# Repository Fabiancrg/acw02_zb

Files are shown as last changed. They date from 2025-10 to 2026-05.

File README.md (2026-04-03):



| Supported Targets | ESP32-C6 | ESP32-H2 |
| --- |  --- | --- |

# ACW02-ZB Zigbee HVAC Thermostat Controller




# Project Description
ACW02-ZB is an open-source Zigbee-enabled HVAC controller for the Airton (to replace ACW02 WiFi module) series and compatible units. It allows full integration with Zigbee2MQTT, Home Assistant, and other Zigbee ecosystems, providing remote control, monitoring, and diagnostics for air conditioning systems.

### Key Features
- **Zigbee 3.0 End Device**: Compatible with ESP32-C6 and ESP32-H2
- **Full HVAC Control**: Supports on/off, mode, setpoints, fan speed, swing, eco, night, mute, and display
- **Error Diagnostics**: Exposes AC error codes and status via Zigbee attributes (Only one cade currently)
- **Automatic Polling**: Uses Z2M's generic polling framework for unreportable attributes
- **Auto-Rejoin**: Device automatically rejoins Zigbee network after removal or network loss
- **Clean Entity Names**: Optimized for Home Assistant and Zigbee2mqtt UI
- **Factory Reset**: Long-press boot button 5s for full reset
- **Open Hardware**: PCB and schematic files included (Using Seeedstudio Xiao ESP32-C6)

### Architecture
- **Firmware**: ESP-IDF C code for Zigbee stack, HVAC protocol, and attribute mapping
- **External Converter**: Custom Zigbee2MQTT JS converter for multi-endpoint mapping and polling

### Typical Use Cases
- Integrate Airton (to replace ACW02 WiFi module) with Home Assistant via Zigbee2MQTT
- Monitor and control HVAC remotely (mode, temperature, fan, swing, eco, etc.)
- Receive error codes and filter status for maintenance
- Automatic recovery from network disruptions

### Getting Started
1. Flash ESP32-C6/H2 with provided firmware
2. Add external converter to Zigbee2MQTT
3. Pair device and configure entities in Home Assistant
4. Use Z2M UI or automations for full control and monitoring

See the documentation files for advanced features, troubleshooting, and hardware details.

### ZHA Support (untested)

The device should also be compatible with **ZHA (Zigbee Home Automation)**. Because it uses standard Zigbee 3.0 clusters, core functionality (climate control, switches) works out of the box. A custom ZHA quirk (`acw02_zb.py`) is provided to handle the non-standard fan mode values and the full 9-endpoint structure.

> **Warning:** ZHA support has **not been tested**. The quirk is provided as a best-effort implementation based on the device's Zigbee descriptor and firmware source. Feedback and contributions are welcome.

> **Note:** Some features available in Zigbee2MQTT require additional HA automations under ZHA — see the [ZHA Integration Guide](ZHA_INTEGRATION_GUIDE.md) for installation steps, known limitations, and workarounds.

---

## PCB

The PCB has been tested for a couple of weeks now on 4 units and is working well.
I am using a Seeedstudio Xiao ESP32-C6 with a custom buck converter (based on a MPS MP1584) and a level shifter for TX/RX (using a Texas Instrument TXB0102)
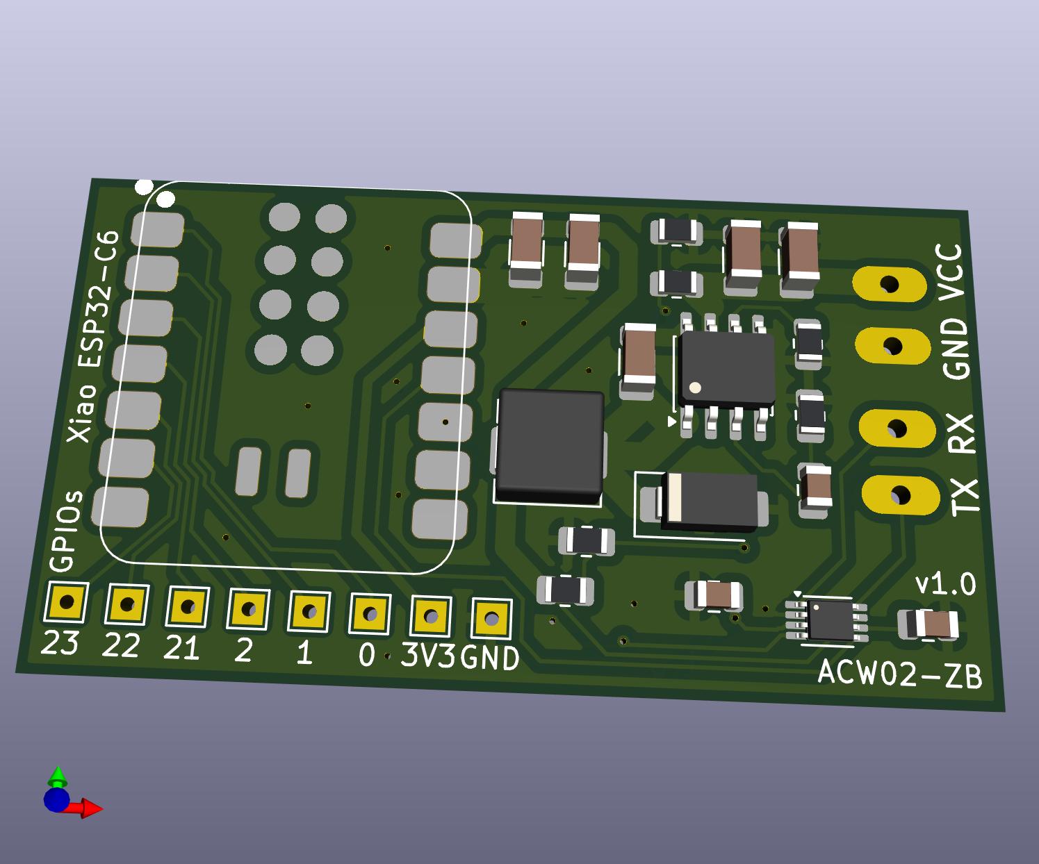
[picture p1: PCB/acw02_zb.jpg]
ACW02-ZB Render

ACW02-ZB
ACW02-ZB

PCB is small, 48mm x 27mm so there is no problem to fit it inside the unit.
---

## 🙌 Credits

- Original HVAC reverse‑engineering and ESPHome work: [devildant/acw02_esphome](https://github.com/devildant/acw02_esphome)  
- Zigbee2MQTT ecosystem: [Koenkk/zigbee2mqtt](https://github.com/Koenkk/zigbee2mqtt) and [zigbee-herdsman-converters](https://github.com/Koenkk/zigbee-herdsman-converters)

## 🛡️ License

This repository uses multiple licenses depending on content type:

- **Code** (`*.yaml`, `*.cpp`, `*.h`) — [GNU GPLv3](./LICENSE)  
- **PCB files** (`*.zip`, `*.json`) — [CC BY-NC-SA 4.0](./LICENSE-hardware)

---

# ⚠️ Disclaimer

This project is provided as-is, without any warranty or guarantee of fitness for a particular purpose. Use at your own risk. The authors and contributors are not responsible for any damage, malfunction, or loss resulting from the use, modification, or installation of this hardware or software.

- This is an open-source, community-driven project intended for educational and experimental use.
- The hardware and firmware are not certified for commercial or safety-critical applications.
- Always follow proper electrical safety procedures when working with HVAC systems and mains power.
- Modifying or installing this project may void your equipment warranty.
- Ensure compliance with local laws and regulations regarding wireless devices and HVAC modifications.

By using this project, you acknowledge and accept these terms.

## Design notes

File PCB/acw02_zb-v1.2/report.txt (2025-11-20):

Front (top side) placement file: 'C:\Users\fabia\My Drive\Devel\KiCAD\Project\acw02_zb\JLPCB\acw02_zb-top-pos.csv'.
Info: Component count: 22.
Back (bottom side) placement file: 'C:\Users\fabia\My Drive\Devel\KiCAD\Project\acw02_zb\JLPCB\acw02_zb-bottom-pos.csv'.
Info: Component count: 0.
Info: Full component count: 22.
Info: Done.

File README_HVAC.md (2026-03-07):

# Zigbee HVAC Thermostat Controller

This project implements a Zigbee End Device that controls an HVAC unit via UART and exposes it as a standard Zigbee thermostat.

## Hardware Requirements

- ESP32-C6 development board
- ACW02 HVAC unit (or compatible)
- UART connection (TX/RX pins 16/17)

## Features

The Zigbee thermostat exposes the following capabilities:

### Standard Thermostat Cluster (0x0201)
- **System Mode**: Off, Auto, Cool, Heat, Dry, Fan
- **Temperature Control**: 16-31°C (configurable setpoint)
- **Local Temperature**: Current room temperature from HVAC unit
- **Occupied Cooling/Heating Setpoint**: Target temperature

### Fan Control Cluster (0x0202)
- **Fan Mode**: Auto, Low, Medium, High, Smart/Max

### Custom Attributes (Manufacturer-Specific)
- **Eco Mode** (0xF000): Energy-saving mode (only works in Cool mode)
- **Swing Mode** (0xF001): Vertical air flow swing
- **Display** (0xF002): HVAC unit display on/off
- **Error Text** (0xF003): Error messages from HVAC unit

## UART Protocol

The device communicates with the HVAC unit using a proprietary protocol at 9600 baud:

- **TX Pin**: GPIO 16
- **RX Pin**: GPIO 17
- **Baud Rate**: 9600
- **Data Bits**: 8
- **Parity**: None
- **Stop Bits**: 1

### Frame Format

All frames start with `0x7A 0x7A` and end with a 16-bit CRC.

**Command Frame (28 bytes)**:
```
[0x7A][0x7A][Header][Mode][Temp][Fan][Swing][Options][...][CRC_H][CRC_L]
```

**Status Request (13 bytes)**:
```
0x7A 0x7A 0x21 0xD5 0x0C 0x00 0x00 0xA2 0x0A 0x0A 0xFE 0x29
```

**Keepalive (13 bytes)**:
```
0x7A 0x7A 0x21 0xD5 0x0C 0x00 0x00 0xAB 0x0A 0x0A 0xFC 0xF9
```

## Project Structure

```
acw02_zb/
├── main/
│   ├── esp_zb_hvac.c          # Main Zigbee application
│   ├── esp_zb_light.h         # Zigbee configuration header
│   ├── hvac_driver.c          # HVAC UART driver implementation
│   ├── hvac_driver.h          # HVAC driver header
│   ├── CMakeLists.txt         # Component build configuration
│   └── idf_component.yml      # Component dependencies
├── CMakeLists.txt             # Project CMakeLists
├── sdkconfig                  # ESP-IDF configuration
└── README.md                  # This file
```

## Building and Flashing

1. Set up ESP-IDF v5.5.3 or later
2. Configure the project:
   ```bash
   idf.py set-target esp32c6
   idf.py menuconfig
   ```
3. Build the project:
   ```bash
   idf.py build
   ```
4. Flash to device:
   ```bash
   idf.py -p COMx flash monitor
   ```

## Configuration

### Zigbee Configuration

The device is configured as a Zigbee End Device (ZED):
- **Endpoint**: 1
- **Profile**: Home Automation (0x0104)
- **Device ID**: Thermostat (0x0301)
- **Channel Mask**: All channels

### HVAC Settings

Temperature range: 16-31°C (mapped to 61-88°F internally)

### Joining the Network

On first boot, the device will automatically enter network steering mode. The LED will blink while searching for a network. Once joined, the device will save the network credentials and automatically rejoin on subsequent boots.

## Usage

### From Zigbee Coordinator (e.g., Zigbee2MQTT, Home Assistant)

1. Put your coordinator in pairing mode
2. Power on the ESP32-C6 device
3. Wait for the device to join (check logs)
4. The thermostat will appear with the following entities:
   - System Mode (Off/Auto/Cool/Heat/Dry/Fan)
   - Target Temperature (16-31°C)
   - Current Temperature
   - Fan Speed
   - Eco Mode switch
   - Swing Mode switch
   - Display switch
   - Error status

### Control Examples

**Set cooling mode at 24°C:**
- Set system_mode = "cool"
- Set occupied_cooling_setpoint = 2400 (24.00°C in centidegrees)

**Enable eco mode:**
- Set eco_mode attribute (0xF000) = true
- Note: Only works when system_mode is "cool"

**Adjust fan speed:**
- Set fan_mode in Fan Control cluster

## Removed Features

This project was adapted from the `ZigbeeMultiSensor` example. The following endpoints and features were removed:

- ❌ BME280 environmental sensor endpoint
- ❌ LED strip control endpoint
- ❌ GPIO LED control endpoint
- ❌ Button sensor endpoint
- ❌ Rain gauge sensor endpoint

All sensor and LED control logic has been replaced with HVAC thermostat functionality.

## HVAC Driver Details

### State Management

The driver maintains a local copy of the HVAC state and synchronizes it with:
1. Commands sent to the HVAC unit via UART
2. Status responses received from the HVAC unit
3. Zigbee attribute updates

### Periodic Updates

- **Status Request**: Every 30 seconds
- **Keepalive**: Every 60 seconds
- **Zigbee Sync**: After every state change + periodic updates

### Error Handling

- CRC validation on all received frames
- Retry logic for failed commands (future enhancement)
- Error text attribute reports HVAC errors to coordinator

## Troubleshooting

### Device won't join network
- Check that Zigbee coordinator is in pairing mode
- Verify ESP32-C6 is powered correctly
- Check serial logs for error messages
- Try factory reset (hold button during boot - if button is implemented)

### HVAC not responding
- Verify UART wiring (TX ↔ RX crossover)
- Check baud rate is 9600
- Monitor UART traffic in logs
- Verify HVAC unit is powered on

### Temperature not updating
- HVAC may not report ambient temperature in all modes
- Check that status requests are being sent every 30s
- Verify frame CRC is correct

## License

This code is based on Espressif's Zigbee examples and inherits their licensing.

## Credits

- Base Zigbee framework: Espressif ESP-IDF examples
- HVAC protocol: Reverse-engineered from ACW02 ESPHome component
- Original ESPHome component: See `CodeToReusePartially/acw02_esphome/`

## Future Enhancements

- [ ] Add button for factory reset
- [ ] Implement command retry logic
- [ ] Add OTA firmware update support
- [ ] Support horizontal swing control
- [ ] Add night mode support
- [ ] Implement filter status monitoring
- [ ] Add clean mode support

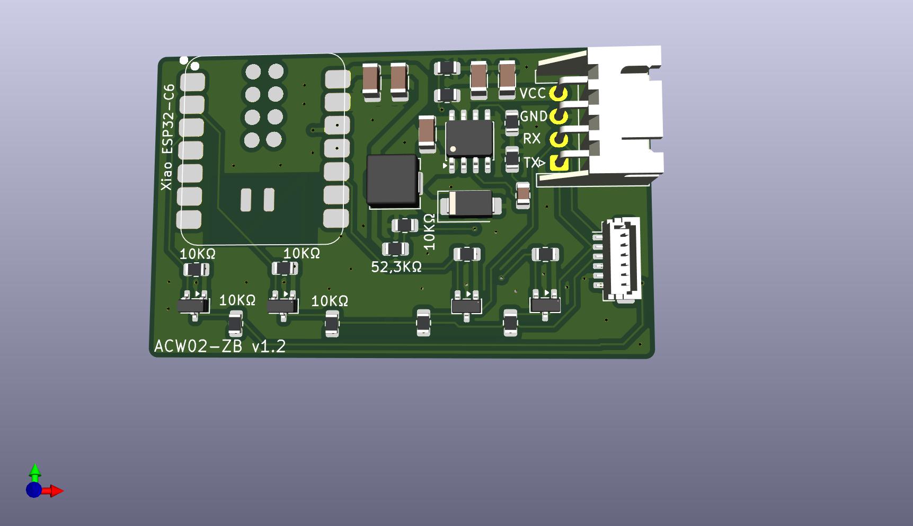
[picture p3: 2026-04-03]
PCB/acw02_zb-v1.2/acw02_zb-v1.2.jpg

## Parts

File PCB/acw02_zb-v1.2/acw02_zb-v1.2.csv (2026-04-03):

Id | Designator | Footprint | Quantity | Designation | Supplier and ref
1 | D1 | D_SMA | 1 | SS34
2 | U1 | XIAO-ESP32C6-SMD | 1 | XIAO-ESP32-S3-SMD
3 | R10,R11,R13,R9,R14,R8,R12,R6,R7,R3 | R_0805_2012Metric | 10 | 10K
4 | R1 | R_0805_2012Metric | 1 | 100K
5 | C6 | C_0805_2012Metric | 1 | 220pF
6 | C5,C3,C8 | C_1206_3216Metric | 3 | 100nF
7 | L1 | L_APV_APH0530 | 1 | 10µH
8 | Q3,Q1,Q4,Q2 | SOT-23 | 4 | BSS138
9 | R5 | R_0805_2012Metric | 1 | 52.3K
10 | J6 | JST_SH_BM06B-SRSS-TB_1x06-1MP_P1.00mm_Vertical | 1 | Conn_01x06_Pin
11 | U3 | SOIC-8-1EP_3.9x4.9mm_P1.27mm_EP2.29x3mm | 1 | MP1584EN-LF-Z
12 | C2 | C_1206_3216Metric | 1 | 10µF-25V
13 | R4 | R_0805_2012Metric | 1 | 200K
14 | C7 | C_1206_3216Metric | 1 | 22µF-10V
15 | R2 | R_0805_2012Metric | 1 | 24.9K
16 | J1 | JST_XH_S4B-XH-A_1x04_P2.50mm_Horizontal | 1 | Conn_01x04_Socket

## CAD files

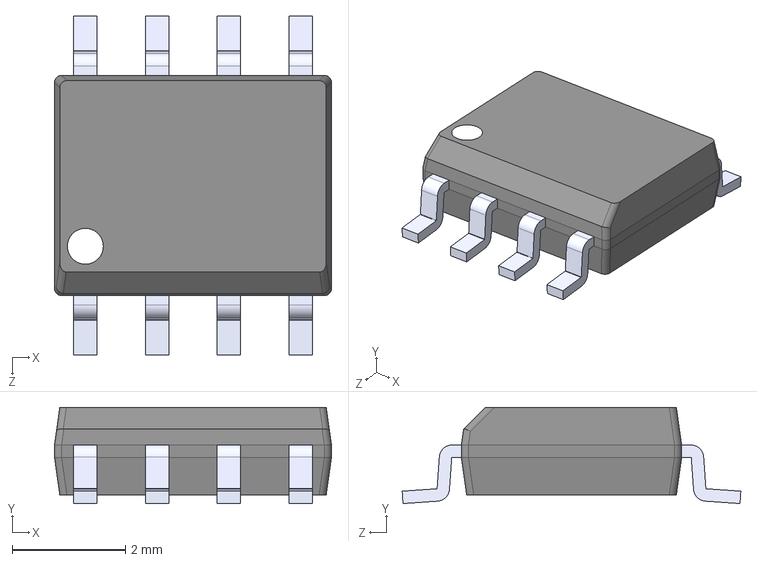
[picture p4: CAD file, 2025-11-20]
PCB/acw02_zb-v1.2/MP1584EN-LF-Z.step
4.90 x 1.70 x 5.99 mm

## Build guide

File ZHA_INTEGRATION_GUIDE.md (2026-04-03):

# ZHA Integration Guide - ACW02-ZB HVAC Thermostat

## Overview

The ACW02-ZB firmware uses standard Zigbee 3.0 clusters, so ZHA can discover and partially control the device out of the box. However, the custom multi-endpoint structure and non-standard fan mode values require a custom quirk for full functionality.

## Files

- **acw02_zb.py** — ZHA custom quirk (device signature + custom fan mode enum)

## Installation

### 1. Copy the quirk file

Create a directory for custom ZHA quirks in your Home Assistant config folder (if it doesn't exist):

```
/config/custom_zha_quirks/acw02_zb.py
```

### 2. Configure Home Assistant

Add the following to your `configuration.yaml`:

```yaml
zha:
  custom_quirks_path: /config/custom_zha_quirks
```

### 3. Restart and re-interview

Restart Home Assistant, then in the ZHA integration UI, select the ACW02-ZB device and click **Reconfigure** (re-interview) to apply the quirk.

---

## Device Endpoints

| Endpoint | Function | HA Entity Type | Notes |
|---|---|---|---|
| EP1 | Thermostat + Fan control | Climate | Main HVAC control |
| EP2 | Eco mode | Switch | |
| EP3 | Swing mode | Switch | |
| EP4 | Display on/off | Switch | |
| EP5 | Night / sleep mode | Switch | |
| EP6 | Air purifier / ionizer | Switch | |
| EP7 | Filter clean status | Switch (read-only) | Do not toggle — see note |
| EP8 | Mute beep sounds | Switch | |
| EP9 | AC error status | Switch (read-only) | Do not toggle — see note |

---

## What Works vs Zigbee2MQTT

| Feature | Zigbee2MQTT | ZHA with quirk |
|---|---|---|
| Climate modes (off/cool/heat/dry/fan_only) | ✅ | ✅ Standard Zigbee SystemMode values match |
| Temperature reading | ✅ | ✅ |
| Temperature setpoint | ✅ | ✅ |
| Eco / Swing / Display / Night / Purifier / Mute | ✅  | ✅ As switch entities |
| Fan speed labels in climate entity | ✅ custom converter | ⚠️ Labels incorrect — see note |
| EP7 clean status as binary sensor | ✅ | ⚠️ Appears as switch — disable in HA |
| EP9 error status as binary sensor | ✅ | ⚠️ Appears as switch — disable in HA |
| Error text (locationDesc) | ✅ Sensor entity | ⚠️ Manual poll required |
| runningMode / fanMode polling | ✅ Built-in | ⚠️ Manual automation required |

---

## Known Limitations and Workarounds

### Fan speed labels in climate entity

The ACW02 firmware uses non-standard fan mode values that differ from the Zigbee spec:

| Value | ACW02 label | Zigbee spec label (shown without quirk) |
|---|---|---|
| 0x00  | Auto | Off |
| 0x01  | Low (P20) | Low ← coincidentally correct |
| 0x02  | Low-Med (P40)  | Medium ← close |
| 0x03  | Medium (P60) | High ← wrong |
| 0x04  | Med-High (P80) | On ← wrong |
| 0x05  | High (P100) | Auto ← wrong |
| 0x06  | Quiet / SILENT | Smart ← wrong |

The quirk corrects the attribute inspector view in ZHA, but the **climate entity** fan mode labels remain incorrect because ZHA's HVAC cluster handler uses the standard enum internally. To set fan speed from an automation, use the raw integer value:

```yaml
service: zha.set_attribute_value
data:
  ieee: "<device_ieee>"
  endpoint_id: 1
  cluster_id: 514        # 0x0202 hvacFanCtrl
  cluster_type: in
  attribute: 0           # fan_mode
  value: 3               # 3 = Medium (P60)
```

### EP7 and EP9 — read-only binary sensors

ZHA creates switch entities for EP7 (filter clean status) and EP9 (AC error status) because they use the standard `genOnOff` cluster. These are driven by the AC unit and are read-only — writing to them has no effect.

**Recommended:** disable these switch entities in the HA entity registry and create binary sensor template entities instead:

```yaml
template:
  - binary_sensor:
      - name: "ACW02 Filter Clean"
        state: "{{ states('switch.acw02_zb_filter_clean') }}"
        device_class: problem

      - name: "ACW02 Error Status"
        state: "{{ states('switch.acw02_zb_error_status') }}"
        device_class: problem
```

### Error text (locationDescription attribute)

The error message string is stored in the `genBasic` cluster's `locationDescription` attribute (cluster `0x0000`, attribute `0x0010`) on EP1. ZHA does not automatically expose this as a sensor entity.

**Workaround:** use an automation to poll and store the value periodically:

```yaml
automation:
  - alias: "ACW02 Poll Error Text"
    trigger:
      - platform: time_pattern
        minutes: "/1"
    action:
      - service: zha.get_attribute_value
        data:
          ieee: "<device_ieee>"
          endpoint_id: 1
          cluster_id: 0      # genBasic
          cluster_type: in
          attribute: 16      # locationDescription (0x0010)
        response_variable: error_response
      - service: input_text.set_value
        target:
          entity_id: input_text.acw02_error_text
        data:
          value: "{{ error_response.value }}"
```

### Polling for runningMode and fanMode

The ESP-Zigbee stack cannot auto-report `runningMode` (thermostat attribute `0x001E`) and `fanMode` (fan control attribute `0x0000`). Add a 60-second polling automation:

```yaml
automation:
  - alias: "ACW02 Poll Unreportable Attributes"
    trigger:
      - platform: time_pattern
        seconds: "/60"
    action:
      - service: zha.get_attribute_value
        data:
          ieee: "<device_ieee>"
          endpoint_id: 1
          cluster_id: 513    # 0x0201 hvacThermostat
          cluster_type: in
          attribute: 30      # runningMode (0x001E)
      - service: zha.get_attribute_value
        data:
          ieee: "<device_ieee>"
          endpoint_id: 1
          cluster_id: 514    # 0x0202 hvacFanCtrl
          cluster_type: in
          attribute: 0       # fanMode
```

---

## Device Pairing

1. Power on the device — it enters pairing mode if factory-new, or long-press the boot button for 5 s to factory reset
2. Enable **Permit joining** in ZHA
3. The device should appear with model `acw02-z` and manufacturer `Custom devices (DiY)`
4. After pairing, trigger a **Reconfigure** to bind all clusters and enable reporting

---

## Hardware

- **MCU:** Seeedstudio XIAO ESP32-C6 (or compatible ESP32-H2)
- **Firmware:** ESP-IDF with ESP-Zigbee SDK
- **Zigbee role:** Router
- **OTA:** Supported (via ZHA OTA provider)

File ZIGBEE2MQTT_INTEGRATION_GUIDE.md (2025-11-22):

# Zigbee2MQTT Integration Guide - ACW02 HVAC Thermostat

## Overview
This guide explains how to integrate the ACW02 HVAC Thermostat converter into the official Zigbee2MQTT repository.

## Files Created
- **acw02-zb.ts** - TypeScript converter definition for upstream contribution
- **acw02-zb.js** - JavaScript converter for local/external use

## Steps to Integrate into Zigbee2MQTT

### 1. Fork and Clone the Repository
```bash
# Fork the repository on GitHub first
git clone https://github.com/YOUR_USERNAME/zigbee-herdsman-converters.git
cd zigbee-herdsman-converters
```

### 2. Create a New Branch
```bash
git checkout -b add-acw02-hvac-thermostat
```

### 3. Add the Device Definition

Open the file: `src/devices/custom_devices_diy.ts`

Add the following import at the top (if not already present):
```typescript
import type {DefinitionWithExtend, Fz, Tz, KeyValue} from '../lib/types';
```

Then add the converter definition to the `definitions` array in `custom_devices_diy.ts`:

```typescript
export const definitions: DefinitionWithExtend[] = [
    // ... existing devices ...
    
    {
        zigbeeModel: ['acw02-z'],
        model: 'ACW02-ZB',
        vendor: 'Custom devices (DiY)',
        description: 'ACW02 HVAC Thermostat Controller via Zigbee (Router)',
        
        meta: {
            multiEndpoint: true,
        },
        
        fromZigbee: [
            fzLocal.acw02_thermostat,
            fzLocal.acw02_fan_mode,
            fzLocal.acw02_clean_status,
            fzLocal.acw02_error_status,
            fz.on_off,
            fzLocal.acw02_error_text,
        ],
        toZigbee: [
            tz.thermostat_local_temperature,
            tz.thermostat_occupied_heating_setpoint,
            tz.thermostat_system_mode,
            tzLocal.acw02_fan_mode,
            tz.on_off,
        ],
        
        exposes: [
            e.climate()
                .withSetpoint('occupied_heating_setpoint', 16, 31, 1)
                .withLocalTemperature()
                .withSystemMode(['off', 'auto', 'cool', 'heat', 'dry', 'fan_only'])
                .withRunningState(['idle', 'heat', 'cool', 'fan_only']),
            exposes.enum('fan_mode', ea.ALL, ['quiet', 'low', 'low-med', 'medium', 'med-high', 'high', 'auto'])
                .withDescription('Fan speed: Quiet=SILENT, Low=P20, Low-Med=P40, Medium=P60, Med-High=P80, High=P100, Auto=AUTO'),
            exposes.text('error_text', ea.STATE_GET)
                .withDescription('Error message from AC unit (read-only)'),
            exposes.binary('ac_error_status', ea.STATE_GET, 'ON', 'OFF')
                .withDescription('Error status indicator (read-only)'),
            e.switch().withEndpoint('eco_mode').withDescription('Eco mode'),
            e.switch().withEndpoint('swing_mode').withDescription('Swing mode'),
            e.switch().withEndpoint('display').withDescription('Display control'),
            e.switch().withEndpoint('night_mode').withDescription('Night/sleep mode'),
            e.switch().withEndpoint('purifier').withDescription('Air purifier/ionizer'),
            exposes.binary('filter_clean_status', ea.STATE_GET, 'ON', 'OFF')
                .withDescription('Filter cleaning reminder (read-only)'),
            e.switch().withEndpoint('mute').withDescription('Mute beep sounds'),
        ],
        
        endpoint: (device) => {
            return {
                'default': 1,
                'eco_mode': 2,
                'swing_mode': 3,
                'display': 4,
                'night_mode': 5,
                'purifier': 6,
                'clean_sensor': 7,
                'mute': 8,
                'error_sensor': 9,
            };
        },
        
        configure: async (device, coordinatorEndpoint, logger) => {
            const endpoint1 = device.getEndpoint(1);
            const endpoint2 = device.getEndpoint(2);
            const endpoint3 = device.getEndpoint(3);
            const endpoint4 = device.getEndpoint(4);
            const endpoint5 = device.getEndpoint(5);
            const endpoint6 = device.getEndpoint(6);
            const endpoint7 = device.getEndpoint(7);
            const endpoint8 = device.getEndpoint(8);
            const endpoint9 = device.getEndpoint(9);
            
            await reporting.bind(endpoint1, coordinatorEndpoint, ['genBasic', 'hvacThermostat', 'hvacFanCtrl']);
            await reporting.thermostatTemperature(endpoint1);
            await reporting.thermostatOccupiedHeatingSetpoint(endpoint1);
            await endpoint1.configureReporting('hvacThermostat', [{
                attribute: 'systemMode',
                minimumReportInterval: 1,
                maximumReportInterval: 300,
                reportableChange: 1,
            }]);
            
            // Configure all switch endpoints
            for (const ep of [endpoint2, endpoint3, endpoint4, endpoint5, endpoint6, endpoint7, endpoint8, endpoint9]) {
                await reporting.bind(ep, coordinatorEndpoint, ['genOnOff']);
                await reporting.onOff(ep);
            }
            
            // Initial read of unreportable attributes
            try {
                await endpoint1.read('hvacThermostat', ['runningMode']);
                await endpoint1.read('genBasic', ['locationDesc']);
                await endpoint1.read('hvacFanCtrl', ['fanMode']);
            } catch (error) {
                logger?.warn(`ACW02: Initial read failed: ${(error as Error).message}`);
            }
        },
        
        extend: [
            m.poll({
                key: "acw02_state",
                option: e.numeric("acw02_poll_interval", ea.SET)
                    .withValueMin(-1)
                    .withDescription("Polling interval in seconds for unreportable attributes (default: 60s, -1 to disable)"),
                defaultIntervalSeconds: 60,
                poll: async (device) => {
                    const endpoint1 = device.getEndpoint(1);
                    if (!endpoint1) return;
                    
                    try {
                        await endpoint1.read('hvacThermostat', ['runningMode']);
                        await endpoint1.read('hvacFanCtrl', ['fanMode']);
                        await endpoint1.read('genBasic', ['locationDesc']);
                    } catch (error) {
                        console.error(`ACW02 polling failed: ${(error as Error).message}`);
                    }
                },
            }),
        ],
        ota: true,
    },
];
```

### 4. Add Custom Converters (fzLocal and tzLocal)

Add these converters to the `fzLocal` and `tzLocal` objects in `custom_devices_diy.ts`:

**In `tzLocal` object:**
```typescript
const tzLocal = {
    // ... existing converters ...
    
    acw02_fan_mode: {
        key: ['fan_mode'],
        convertSet: async (entity, key, value, meta) => {
            const fanModeMap: {[key: string]: number} = {
                'quiet': 0x06, 'low': 0x01, 'low-med': 0x02,
                'medium': 0x03, 'med-high': 0x04, 'high': 0x05, 'auto': 0x00,
            };
            const numericValue = fanModeMap[value as string];
            if (numericValue !== undefined) {
                await entity.write('hvacFanCtrl', {'fanMode': numericValue});
                return {state: {fan_mode: value}};
            }
        },
        convertGet: async (entity, key, meta) => {
            await entity.read('hvacFanCtrl', ['fanMode']);
        },
    } satisfies Tz.Converter,
};
```

**In `fzLocal` object:**
```typescript
const fzLocal = {
    // ... existing converters ...
    
    acw02_fan_mode: {
        cluster: 'hvacFanCtrl',
        type: ['attributeReport', 'readResponse'],
        convert: (model, msg, publish, options, meta) => {
            if (msg.data.hasOwnProperty('fanMode')) {
                const fanModeMap: {[key: number]: string} = {
                    0x00: 'auto', 0x01: 'low', 0x02: 'low-med',
                    0x03: 'medium', 0x04: 'med-high', 0x05: 'high',
                    0x06: 'quiet', 0x0D: 'quiet',
                };
                return {fan_mode: fanModeMap[msg.data.fanMode as number]};
            }
        },
    } satisfies Fz.Converter<'hvacFanCtrl', undefined, ['attributeReport', 'readResponse']>,
    
    acw02_clean_status: {
        cluster: 'genOnOff',
        type: ['attributeReport', 'readResponse'],
        convert: (model, msg, publish, options, meta) => {
            if (msg.endpoint.ID === 7 && msg.data.hasOwnProperty('onOff')) {
                return {filter_clean_status: msg.data['onOff'] === 1 ? 'ON' : 'OFF'};
            }
        },
    } satisfies Fz.Converter<'genOnOff', undefined, ['attributeReport', 'readResponse']>,
    
    acw02_error_status: {
        cluster: 'genOnOff',
        type: ['attributeReport', 'readResponse'],
        convert: (model, msg, publish, options, meta) => {
            if (msg.endpoint.ID === 9 && msg.data.hasOwnProperty('onOff')) {
                return {ac_error_status: msg.data['onOff'] === 1 ? 'ON' : 'OFF'};
            }
        },
    } satisfies Fz.Converter<'genOnOff', undefined, ['attributeReport', 'readResponse']>,
    
    acw02_error_text: {
        cluster: 'genBasic',
        type: ['attributeReport', 'readResponse'],
        convert: (model, msg, publish, options, meta) => {
            if (msg.endpoint.ID === 1 && msg.data['locationDesc'] !== undefined) {
                let errorText = '';
                const locationDesc = msg.data['locationDesc'];
                if (typeof locationDesc === 'string') {
                    errorText = locationDesc;
                } else if (Array.isArray(locationDesc) && locationDesc.length > 0) {
                    const textLength = locationDesc[0];
                    errorText = String.fromCharCode.apply(null, locationDesc.slice(1, 1 + textLength));
                }
                return {error_text: errorText.trim()};
            }
        },
    } satisfies Fz.Converter<'genBasic', undefined, ['attributeReport', 'readResponse']>,
    
    acw02_thermostat: {
        cluster: 'hvacThermostat',
        type: ['attributeReport', 'readResponse'],
        convert: (model, msg, publish, options, meta) => {
            const result: KeyValue = {};
            if (msg.data.hasOwnProperty('localTemp')) {
                result.local_temperature = (msg.data.localTemp as number) / 100;
            }
            if (msg.data.hasOwnProperty('runningMode')) {
                const modeMap: {[key: number]: string} = {
                    0x00: 'idle', 0x03: 'cool', 0x04: 'heat', 0x07: 'fan_only',
                };
                result.running_state = modeMap[msg.data.runningMode as number] || 'idle';
            }
            if (msg.data.hasOwnProperty('systemMode')) {
                const sysModeMap: {[key: number]: string} = {
                    0x00: 'off', 0x01: 'auto', 0x03: 'cool',
                    0x04: 'heat', 0x07: 'fan_only', 0x08: 'dry',
                };
                result.system_mode = sysModeMap[msg.data.systemMode as number] || 'off';
            }
            if (msg.data.hasOwnProperty('occupiedHeatingSetpoint')) {
                result.occupied_heating_setpoint = (msg.data.occupiedHeatingSetpoint as number) / 100;
            } else if (msg.data.hasOwnProperty('occupiedCoolingSetpoint')) {
                result.occupied_heating_setpoint = (msg.data.occupiedCoolingSetpoint as number) / 100;
            }
            return result;
        },
    } satisfies Fz.Converter<'hvacThermostat', undefined, ['attributeReport', 'readResponse']>,
};
```

### 5. Test Locally

```bash
# Build the project
npm ci
npm run build

# The built converter will be in dist/
```

### 6. Commit and Push

```bash
git add src/devices/custom_devices_diy.ts
git commit -m "Add support for ACW02 HVAC Thermostat (Custom devices DiY)

- Multi-endpoint Zigbee HVAC thermostat controller
- Supports temperature control, fan speeds, and multiple switches
- 9 endpoints: main thermostat + eco/swing/display/night/purifier/clean/mute/error
- Custom fan modes: quiet, low, low-med, medium, med-high, high, auto
- Error reporting via locationDesc attribute
- Filter cleaning status indicator
- OTA update support"

git push origin add-acw02-hvac-thermostat
```

### 7. Create Pull Request

1. Go to https://github.com/Koenkk/zigbee-herdsman-converters
2. Click "New Pull Request"
3. Select your branch
4. Fill in the PR template:

**Title:** Add support for ACW02 HVAC Thermostat (Custom devices DiY)

**Description:**
```markdown
## Description
Adds support for ACW02 HVAC Thermostat - a custom DIY Zigbee device based on ESP32-C6.

## Device Details
- **Model:** ACW02-ZB
- **Vendor:** Custom devices (DiY)
- **Zigbee Model ID:** acw02-z
- **Manufacturer Name:** Custom devices (DiY)
- **Device Type:** Router
- **Chip:** ESP32-C6 with ESP-Zigbee SDK

## Features
- **Climate Control:**
  - Temperature setpoint: 16-31°C (single setpoint for both heating/cooling)
  - Local temperature reading
  - System modes: off, auto, cool, heat, dry, fan_only
  - Running state: idle, heat, cool, fan_only

- **Fan Control:**
  - Custom fan speeds: quiet, low, low-med, medium, med-high, high, auto
  - Maps to ACW02 protocol values (SILENT, P20, P40, P60, P80, P100, AUTO)

- **Switches (9 endpoints total):**
  - Eco mode (endpoint 2)
  - Swing mode (endpoint 3)
  - Display control (endpoint 4)
  - Night/sleep mode (endpoint 5)
  - Air purifier/ionizer (endpoint 6)
  - Mute beep sounds (endpoint 8)

- **Read-only Sensors:**
  - Filter cleaning status (endpoint 7)
  - Error status indicator (endpoint 9)
  - Error text messages (via locationDesc attribute)

- **Additional:**
  - OTA firmware updates supported
  - Optimized reporting (most attributes auto-report via REPORTING flag)
  - Minimal polling for unreportable attributes (runningMode, fanMode, error_text)

## Testing
- Tested with Zigbee2MQTT version: [YOUR_VERSION]
- Coordinator: [YOUR_COORDINATOR]
- All features verified working

## Screenshots
[Add screenshots of the device in Zigbee2MQTT UI if possible]
```

## Device Information for Users

Once merged, users can find the device in Zigbee2MQTT as:

**Supported Devices → Custom devices (DiY) → ACW02-ZB**

### Device Pairing
1. Power on the device
2. It will automatically enter pairing mode (factory new)
3. Permit joining in Zigbee2MQTT
4. Device should appear with all endpoints

### Configuration Options
- `acw02_poll_interval`: Polling interval for unreportable attributes (default: 60s, set to -1 to disable)

## External Converter (Temporary Use)

While waiting for PR approval, users can use `acw02-zb.js` as an external converter:

1. Copy `acw02-zb.js` to your Zigbee2MQTT configuration directory
2. Edit `configuration.yaml`:
```yaml
external_converters:
  - acw02-zb.js
```
3. Restart Zigbee2MQTT

## Notes

- **Manufacturer Name:** Device reports "Custom devices (DiY)" matching the Zigbee2MQTT vendor category
- **Multi-endpoint:** Uses 9 endpoints for complete AC control
- **Reporting Optimization:** Most attributes use ESP_ZB_ZCL_ATTR_ACCESS_REPORTING flag for automatic updates
- **Polling:** Only 3 attributes need polling (runningMode, fanMode, error_text) due to ESP-Zigbee stack limitations

## Hardware Information

- **MCU:** ESP32-C6 (XIAO ESP32-C6 board)
- **UART:** Connected to ACW02 AC unit via custom protocol
- **Power:** 5V via USB or direct connection
- **Antenna:** Supports both onboard and external antenna (FM8625H switch)

## Future Enhancements

Potential improvements for future versions:
- Additional error code decoding (currently only CL confirmed)
- TURBO fan mode support (currently mapped to quiet)
- Temperature sensor calibration
- Energy monitoring (if AC supports it)

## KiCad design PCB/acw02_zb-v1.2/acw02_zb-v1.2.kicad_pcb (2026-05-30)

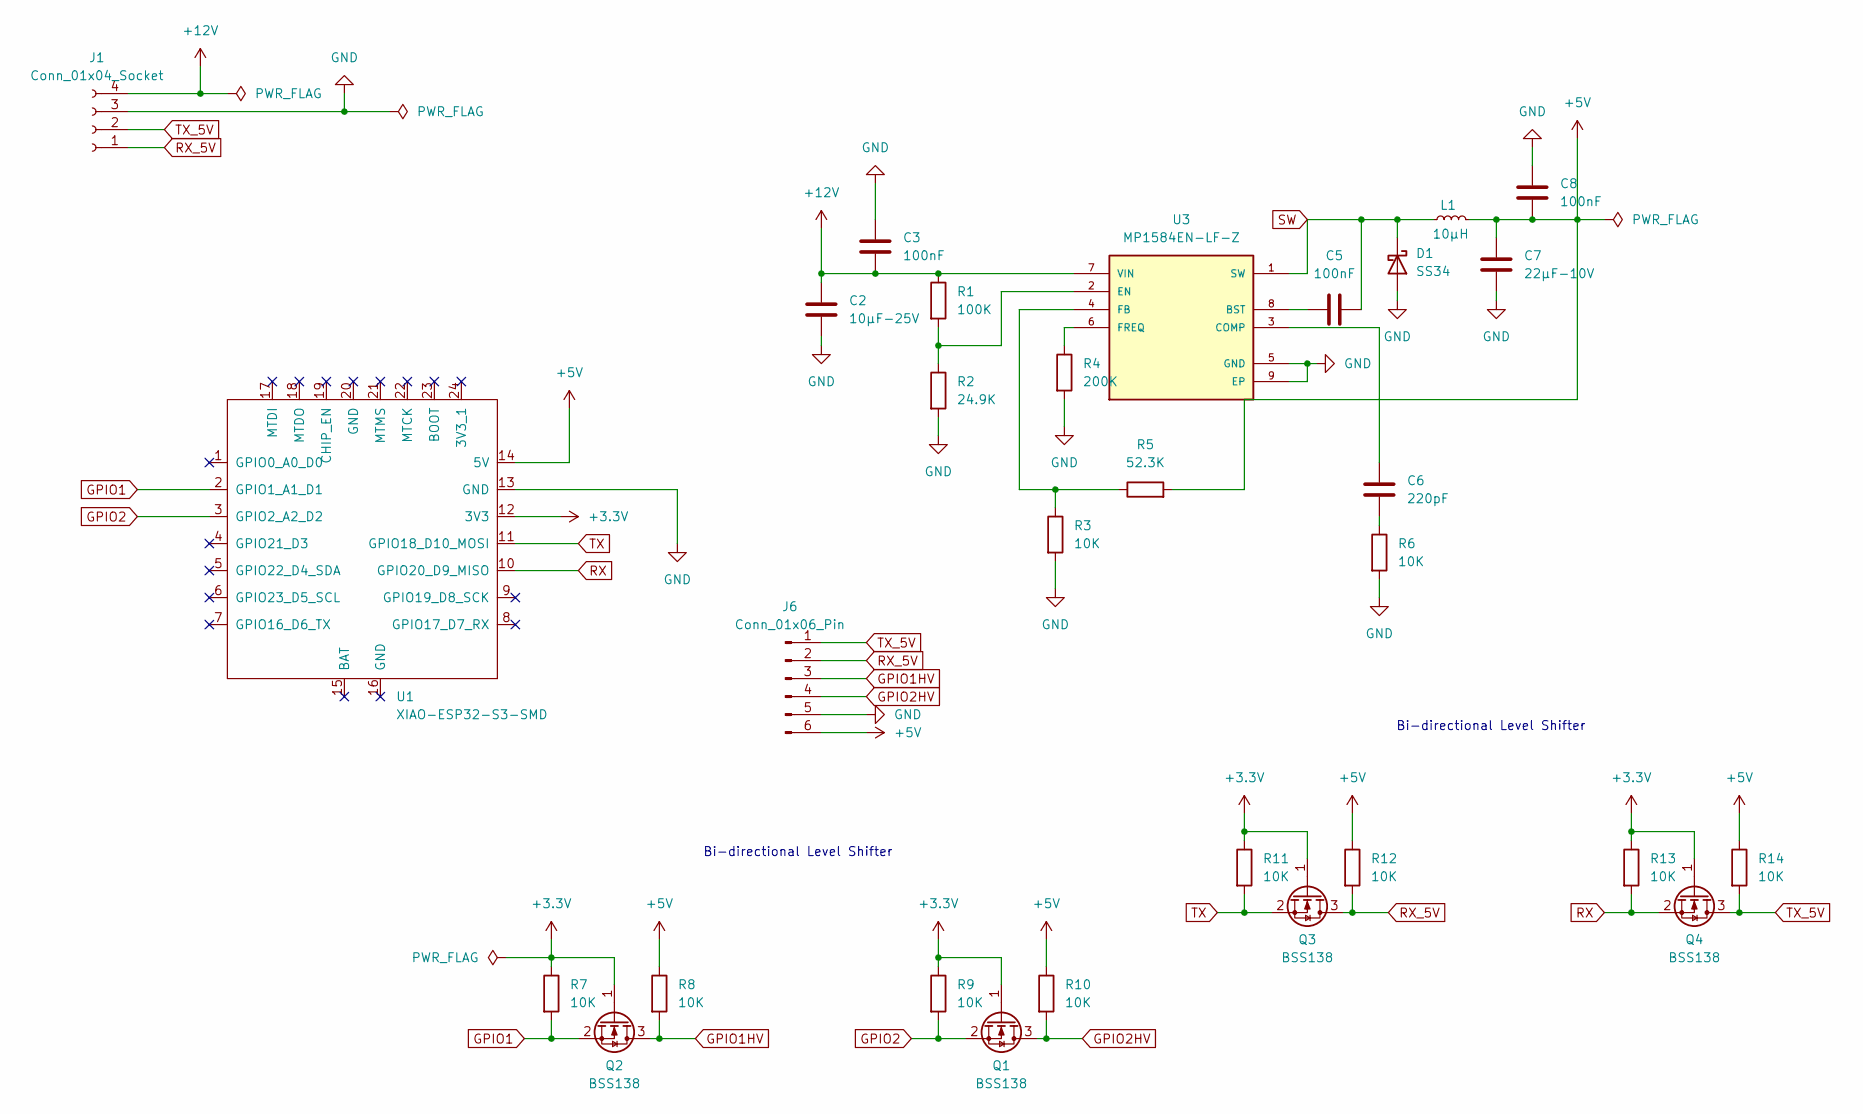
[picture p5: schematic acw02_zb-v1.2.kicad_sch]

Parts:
C2: 10µF-25V; C_1206_3216Metric
C3, C5, C8: 100nF; C_1206_3216Metric
C6: 220pF; C_0805_2012Metric
C7: 22µF-10V; C_1206_3216Metric
D1: SS34; D_SMA
J1: Conn_01x04_Socket; JST_XH_S4B-XH-A_1x04_P2.50mm_Horizontal
J6: Conn_01x06_Pin; JST_SH_BM06B-SRSS-TB_1x06-1MP_P1.00mm_Vertical
L1: 10µH; L_APV_APH0530
Q1, Q2, Q3, Q4: BSS138; SOT-23
R1: 100K; R_0805_2012Metric
R2: 24.9K; R_0805_2012Metric
R3, R6, R7, R8, R9, R10, R11, R12, R13, R14: 10K; R_0805_2012Metric
R4: 200K; R_0805_2012Metric
R5: 52.3K; R_0805_2012Metric
U1: XIAO-ESP32-S3-SMD; XIAO-ESP32C6-SMD
U3: MP1584EN-LF-Z; SOIC-8-1EP_3.9x4.9mm_P1.27mm_EP2.29x3mm

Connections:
+3.3V: Q1.1 (G), Q2.1 (G), Q3.1 (G), Q4.1 (G), R7.1, R9.1, R11.1, R13.1, U1.12 (3V3)
+5V: C7.1, C8.1, J6.6, L1.2, R5.2, R8.1, R10.1, R12.1, R14.1, U1.14 (5V)
+12V: C2.1, C3.1, J1.4, R1.1, U3.7 (VIN)
GND: C2.2, C3.2, C7.2, C8.2, D1.2 (A), J1.3, J6.5, R2.2, R3.2, R4.2, R6.2, U1.13 (GND), U3.5 (GND), U3.9 (EP)
GPIO1: Q2.2 (S), R7.2, U1.2 (GPIO1_A1_D1)
GPIO1HV: J6.3, Q2.3 (D), R8.2
GPIO2: Q1.2 (S), R9.2, U1.3 (GPIO2_A2_D2)
GPIO2HV: J6.4, Q1.3 (D), R10.2
unnamed: C6.2, R6.1
unnamed: C5.1, U3.8 (BST)
unnamed: C6.1, U3.3 (COMP)
unnamed: R1.2, R2.1, U3.2 (EN)
unnamed: R3.1, R5.1, U3.4 (FB)
unnamed: R4.1, U3.6 (FREQ)
RX: Q4.2 (S), R13.2, U1.10 (GPIO20_D9_MISO)
RX_5V: J1.1, J6.2, Q3.3 (D), R12.2
SW: C5.2, D1.1 (K), L1.1, U3.1 (SW)
TX: Q3.2 (S), R11.2, U1.11 (GPIO18_D10_MOSI)
TX_5V: J1.2, J6.1, Q4.3 (D), R14.2

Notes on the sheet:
Bi-directional Level Shifter

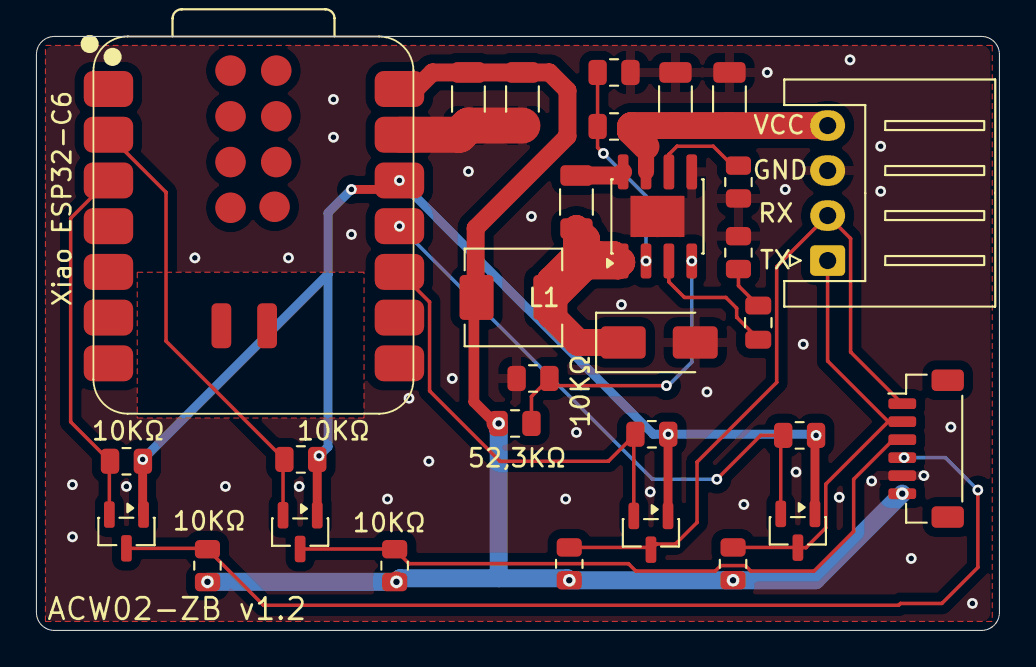
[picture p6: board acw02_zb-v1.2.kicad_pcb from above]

Board: 2 copper layers, 53.5 x 33.0 mm, 30 parts (0 on the bottom side), 19 nets.

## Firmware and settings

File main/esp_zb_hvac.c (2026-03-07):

/*
 * SPDX-FileCopyrightText: 2024 Espressif Systems (Shanghai) CO LTD
 *
 * SPDX-License-Identifier: LicenseRef-Included
 *
 * Zigbee HVAC Thermostat
 *
 * This code controls an HVAC device via UART and exposes it as a Zigbee thermostat
 */
#include "freertos/FreeRTOS.h"
#include "freertos/task.h"
#include "freertos/queue.h"
#include "esp_check.h"
#include "esp_log.h"
#include "nvs_flash.h"
#include "driver/gpio.h"
#include "esp_intr_alloc.h"
#include "board.h"
#include "ha/esp_zigbee_ha_standard.h"
#include "esp_zb_hvac.h"
#include "hvac_driver.h"
#include "esp_zb_ota.h"
#include "esp_zigbee_trace.h"
#include "sdkconfig.h"
#include "esp_ota_ops.h"
#include "esp_system.h"
#include "freertos/timers.h"


#if !defined ZB_ROUTER_ROLE
#error Define ZB_ROUTER_ROLE in idf.py menuconfig to compile Router source code.
#endif

static const char *TAG = "HVAC_ZIGBEE";

/* Keepalive interval - required to maintain UART connection with AC unit */
#define HVAC_KEEPALIVE_INTERVAL_MS  30000  // 30 seconds

/* Boot button configuration for factory reset */
#define BOOT_BUTTON_GPIO            GPIO_NUM_9
#define BUTTON_LONG_PRESS_TIME_MS   5000

/********************* Function Declarations **************************/
static esp_err_t deferred_driver_init(void);
static void hvac_update_zigbee_attributes(uint8_t param);
static void hvac_keepalive_task(uint8_t param);
static esp_err_t button_init(void);
static void button_task(void *arg);
static void factory_reset_device(uint8_t param);

/* OTA validation functions */
void ota_validation_start(void);
void ota_validation_hw_init_ok(void);
void ota_validation_zigbee_init_ok(void);
void ota_validation_zigbee_connected(void);
void ota_validation_mark_invalid(void);

// Helper to fill a Zigbee ZCL string (first byte = length, then chars)
static void fill_zcl_string(char *buf, size_t bufsize, const char *src) {
    size_t len = strlen(src);
    if (len > bufsize - 1) len = bufsize - 1; // Reserve 1 byte for length
    buf[0] = (uint8_t)len;
    memcpy(&buf[1], src, len);
}

/* Factory reset function */
static void factory_reset_device(uint8_t param)
{
    ESP_LOGW(TAG, "[RESET] Performing factory reset...");
    
    /* Perform factory reset - this will clear all Zigbee network settings */
    esp_zb_factory_reset();
    
    ESP_LOGI(TAG, "[RESET] Factory reset successful - device will restart");
    
    /* Restart the device after a short delay */
    vTaskDelay(pdMS_TO_TICKS(1000));
    esp_restart();
}

/* Boot button queue and ISR handler (interrupt-based like working project) */
static QueueHandle_t button_evt_queue = NULL;

static void IRAM_ATTR button_isr_handler(void *arg)
{
    uint32_t gpio_num = BOOT_BUTTON_GPIO;
    xQueueSendFromISR(button_evt_queue, &gpio_num, NULL);
}

/* Button monitoring task */
static void button_task(void *arg)
{
    uint32_t io_num;
    TickType_t press_start_time = 0;
    bool long_press_triggered = false;
    const TickType_t LONG_PRESS_DURATION = pdMS_TO_TICKS(BUTTON_LONG_PRESS_TIME_MS);
    const TickType_t DEBOUNCE_TIME = pdMS_TO_TICKS(50);  // 50ms debounce
    
    ESP_LOGI(TAG, "[BUTTON] Task started - waiting for button events");
    
    for (;;) {
        // Wait for button interrupt
        if (xQueueReceive(button_evt_queue, &io_num, portMAX_DELAY)) {
            // Debounce delay
            vTaskDelay(DEBOUNCE_TIME);
            
            // Disable interrupts during handling
            gpio_intr_disable(BOOT_BUTTON_GPIO);
            
            // Check button state
            int button_level = gpio_get_level(BOOT_BUTTON_GPIO);
            
            if (button_level == 0) {  // Button pressed (falling edge)
                press_start_time = xTaskGetTickCount();
                long_press_triggered = false;
                ESP_LOGI(TAG, "[BUTTON] Pressed - hold 5 sec for factory reset");
                
                // Wait while button is held with timeout to prevent infinite loop
                TickType_t poll_count = 0;
                const TickType_t MAX_POLL_TIME = pdMS_TO_TICKS(10000);  // 10s max
                
                while (gpio_get_level(BOOT_BUTTON_GPIO) == 0 && poll_count < MAX_POLL_TIME) {
                    TickType_t current_time = xTaskGetTickCount();
                    if ((current_time - press_start_time) >= LONG_PRESS_DURATION && !long_press_triggered) {
                        long_press_triggered = true;
                        ESP_LOGW(TAG, "[BUTTON] Long press detected! Triggering factory reset...");
                        // Schedule factory reset in Zigbee context
                        esp_zb_scheduler_alarm((esp_zb_callback_t)factory_reset_device, 0, 100);
                    }
                    vTaskDelay(pdMS_TO_TICKS(100));
                    poll_count += pdMS_TO_TICKS(100);
                }
                
                // Button released
                if (!long_press_triggered) {
                    uint32_t press_duration = pdTICKS_TO_MS(xTaskGetTickCount() - press_start_time);
                    ESP_LOGI(TAG, "[BUTTON] Released (held for %lu ms)", press_duration);
                }
            }
            
            // Re-enable interrupts after debounce
            vTaskDelay(DEBOUNCE_TIME);
            gpio_intr_enable(BOOT_BUTTON_GPIO);
        }
    }
}

/* Initialize boot button with interrupt-based handling */
static esp_err_t button_init(void)
{
    ESP_LOGI(TAG, "[INIT] Initializing boot button on GPIO%d", BOOT_BUTTON_GPIO);
    
    // Configure GPIO
    gpio_config_t io_conf = {
        .intr_type = GPIO_INTR_NEGEDGE,  // Interrupt on button press (falling edge)
        .pin_bit_mask = (1ULL << BOOT_BUTTON_GPIO),
        .mode = GPIO_MODE_INPUT,
        .pull_up_en = GPIO_PULLUP_ENABLE,
        .pull_down_en = GPIO_PULLDOWN_DISABLE,
    };
    
    esp_err_t ret = gpio_config(&io_conf);
    if (ret != ESP_OK) {
        ESP_LOGE(TAG, "[ERROR] Failed to configure GPIO: %s", esp_err_to_name(ret));
        return ret;
    }
    ESP_LOGI(TAG, "[OK] GPIO configured");
    
    // Create event queue
    button_evt_queue = xQueueCreate(10, sizeof(uint32_t));
    if (!button_evt_queue) {
        ESP_LOGE(TAG, "[ERROR] Failed to create event queue");
        return ESP_FAIL;
    }
    ESP_LOGI(TAG, "[OK] Event queue created");
    
    // Install GPIO ISR service (may already be installed, that's OK)
    esp_err_t isr_ret = gpio_install_isr_service(ESP_INTR_FLAG_DEFAULT);
    if (isr_ret != ESP_OK && isr_ret != ESP_ERR_INVALID_STATE) {
        ESP_LOGE(TAG, "[ERROR] Failed to install ISR service: %s", esp_err_to_name(isr_ret));
        return isr_ret;
    }
    ESP_LOGI(TAG, "[OK] ISR service ready");
    
    // Add ISR handler
    ret = gpio_isr_handler_add(BOOT_BUTTON_GPIO, button_isr_handler, NULL);
    if (ret != ESP_OK) {
        ESP_LOGE(TAG, "[ERROR] Failed to add ISR handler: %s", esp_err_to_name(ret));
        return ret;
    }
    ESP_LOGI(TAG, "[OK] ISR handler added");
    
    // Create button task
    BaseType_t task_ret = xTaskCreate(button_task, "button_task", 2048, NULL, 10, NULL);
    if (task_ret != pdPASS) {
        ESP_LOGE(TAG, "[ERROR] Failed to create button task");
        return ESP_FAIL;
    }
    ESP_LOGI(TAG, "[OK] Button task created");
    
    ESP_LOGI(TAG, "[OK] Boot button initialization complete");
    return ESP_OK;
}

/* Callback function for UART state changes - triggers immediate Zigbee update */
static void hvac_uart_state_changed_callback(void)
{
    /* Schedule immediate Zigbee attribute update (runs in Zigbee task context)
     * This ensures physical remote changes are reflected instantly */
    esp_zb_scheduler_alarm((esp_zb_callback_t)hvac_update_zigbee_attributes, 0, 100);
}

static esp_err_t deferred_driver_init(void)
{
    ESP_LOGI(TAG, "[INIT] Starting deferred driver initialization...");
    
    /* Initialize boot button for factory reset */
    ESP_LOGI(TAG, "[INIT] Initializing boot button...");
    esp_err_t button_ret = button_init();
    if (button_ret != ESP_OK) {
        ESP_LOGE(TAG, "[ERROR] Button initialization failed");
        return button_ret;
    }
    ESP_LOGI(TAG, "[INIT] Boot button initialization complete");
    
    /* Small delay to ensure logs are flushed */
    vTaskDelay(pdMS_TO_TICKS(10));
    
    /* Initialize HVAC UART driver */
    ESP_LOGI(TAG, "[INIT] Initializing HVAC UART driver...");
    ESP_LOGI(TAG, "[INIT] About to call hvac_driver_init()");
    esp_err_t ret = ESP_OK;
    
    // Wrap HVAC init in try-catch equivalent to prevent crashes
    ret = hvac_driver_init();
    
    if (ret != ESP_OK) {
        ESP_LOGE(TAG, "[ERROR] Failed to initialize HVAC driver: %s", esp_err_to_name(ret));
        ESP_LOGW(TAG, "[WARN] Continuing without HVAC - endpoints will still be created");
        // Don't fail - we can still expose Zigbee endpoints without HVAC connected
    } else {
        ESP_LOGI(TAG, "[OK] HVAC driver initialized successfully");
        
        /* Register callback for instant state change notifications from UART */
        ESP_LOGI(TAG, "[INIT] Registering UART state change callback...");
        hvac_register_state_change_callback(hvac_uart_state_changed_callback);
        ESP_LOGI(TAG, "[OK] UART state change callback registered - physical remote changes will be instant");
    }
    
    ESP_LOGI(TAG, "[INIT] Deferred initialization complete");
    return ESP_OK;
}

static void bdb_start_top_level_commissioning_cb(uint8_t mode_mask)
{
    ESP_RETURN_ON_FALSE(esp_zb_bdb_start_top_level_commissioning(mode_mask) == ESP_OK, , 
                       TAG, "Failed to start Zigbee commissioning");
}

void esp_zb_app_signal_handler(esp_zb_app_signal_t *signal_struct)
{
    uint32_t *p_sg_p = signal_struct->p_app_signal;
    esp_err_t err_status = signal_struct->esp_err_status;
    esp_zb_app_signal_type_t sig_type = *p_sg_p;
    
    switch (sig_type) {
    case ESP_ZB_ZDO_SIGNAL_SKIP_STARTUP:
        ESP_LOGI(TAG, "[JOIN] Initialize Zigbee stack");
        esp_zb_bdb_start_top_level_commissioning(ESP_ZB_BDB_MODE_INITIALIZATION);
        break;
        
    case ESP_ZB_BDB_SIGNAL_DEVICE_FIRST_START:
        ESP_LOGI(TAG, "[JOIN] Device first start - factory new device");
        if (err_status == ESP_OK) {
            ESP_LOGI(TAG, "[JOIN] Calling deferred driver initialization...");
            esp_err_t init_ret = deferred_driver_init();
            ESP_LOGI(TAG, "[JOIN] Deferred driver initialization %s (ret=%d)", 
                    init_ret == ESP_OK ? "successful" : "failed", init_ret);
            ESP_LOGI(TAG, "[JOIN] Starting network steering (searching for coordinator)...");
            esp_zb_bdb_start_top_level_commissioning(ESP_ZB_BDB_MODE_NETWORK_STEERING);
            ESP_LOGI(TAG, "[JOIN] Network steering initiated");
        } else {
            ESP_LOGW(TAG, "[JOIN] Failed to initialize Zigbee stack (status: %s)", 
                    esp_err_to_name(err_status));
        }
        break;
        
    case ESP_ZB_BDB_SIGNAL_DEVICE_REBOOT:
        ESP_LOGI(TAG, "[JOIN] Device reboot - previously joined network");
        if (err_status == ESP_OK) {
            ESP_LOGI(TAG, "[JOIN] Calling deferred driver initialization...");
            esp_err_t init_ret = deferred_driver_init();
            ESP_LOGI(TAG, "[JOIN] Deferred driver initialization %s (ret=%d)", 
                    init_ret == ESP_OK ? "successful" : "failed", init_ret);
            
            if (esp_zb_bdb_is_factory_new()) {
                ESP_LOGI(TAG, "[JOIN] Factory new - starting network steering...");
                esp_zb_bdb_start_top_level_commissioning(ESP_ZB_BDB_MODE_NETWORK_STEERING);
            } else {
                ESP_LOGI(TAG, "[JOIN] Rejoining previous network...");
                esp_zb_ieee_addr_t ieee_addr;
                esp_zb_get_long_address(ieee_addr);
                ESP_LOGI(TAG, "[JOIN] IEEE Address: %02x:%02x:%02x:%02x:%02x:%02x:%02x:%02x",
                         ieee_addr[7], ieee_addr[6], ieee_addr[5], ieee_addr[4],
                         ieee_addr[3], ieee_addr[2], ieee_addr[1], ieee_addr[0]);
            }
        } else {
            ESP_LOGW(TAG, "[JOIN] Failed to initialize Zigbee stack (status: %s)", 
                    esp_err_to_name(err_status));
        }
        break;
        
    case ESP_ZB_ZDO_SIGNAL_LEAVE:
        ESP_LOGW(TAG, "[LEAVE] *** DEVICE LEFT THE NETWORK ***");
        if (err_status == ESP_OK) {
            esp_zb_zdo_signal_leave_params_t *leave_params = 
                (esp_zb_zdo_signal_leave_params_t *)esp_zb_app_signal_get_params(p_sg_p);
            
            if (leave_params) {
                ESP_LOGW(TAG, "[LEAVE] Leave type: %s", 
                        leave_params->leave_type == 0 ? "RESET (no rejoin)" : "REJOIN");
                
                if (leave_params->leave_type == 0) {
                    // Device was removed from coordinator (factory reset type leave)
                    ESP_LOGW(TAG, "[LEAVE] Device was removed from the coordinator");
                    ESP_LOGW(TAG, "[LEAVE] Waiting 30 seconds before attempting to rejoin...");
                    
                    // Schedule rejoin after 30 seconds
                    esp_zb_scheduler_alarm((esp_zb_callback_t)bdb_start_top_level_commissioning_cb,
                                          ESP_ZB_BDB_MODE_NETWORK_STEERING, 30000);
                    
                    ESP_LOGI(TAG, "[LEAVE] Auto-rejoin scheduled in 30 seconds");
                } else {
                    // Leave with rejoin flag - device will rejoin automatically
                    ESP_LOGI(TAG, "[LEAVE] Leave with rejoin - device will rejoin automatically");
                }
            } else {
                ESP_LOGW(TAG, "[LEAVE] No leave parameters available");
                ESP_LOGW(TAG, "[LEAVE] Scheduling rejoin attempt in 30 seconds...");
                esp_zb_scheduler_alarm((esp_zb_callback_t)bdb_start_top_level_commissioning_cb,
                                      ESP_ZB_BDB_MODE_NETWORK_STEERING, 30000);
            }
        } else {
            ESP_LOGE(TAG, "[LEAVE] Leave error: %s", esp_err_to_name(err_status));
        }
        break;
        
    case ESP_ZB_BDB_SIGNAL_STEERING:
        ESP_LOGI(TAG, "[JOIN] Steering signal received (status: %s)", esp_err_to_name(err_status));
        if (err_status == ESP_OK) {
            esp_zb_ieee_addr_t extended_pan_id;
            esp_zb_get_extended_pan_id(extended_pan_id);
            ESP_LOGI(TAG, "[JOIN] *** SUCCESSFULLY JOINED NETWORK ***");
            ESP_LOGI(TAG, "[JOIN] Extended PAN ID: %02x:%02x:%02x:%02x:%02x:%02x:%02x:%02x",
                     extended_pan_id[7], extended_pan_id[6], extended_pan_id[5], extended_pan_id[4],
                     extended_pan_id[3], extended_pan_id[2], extended_pan_id[1], extended_pan_id[0]);
            ESP_LOGI(TAG, "[JOIN] PAN ID: 0x%04hx", esp_zb_get_pan_id());
            ESP_LOGI(TAG, "[JOIN] Channel: %d", esp_zb_get_current_channel());
            ESP_LOGI(TAG, "[JOIN] Short Address: 0x%04hx", esp_zb_get_short_address());
            
            esp_zb_ieee_addr_t ieee_addr;
            esp_zb_get_long_address(ieee_addr);
            ESP_LOGI(TAG, "[JOIN] IEEE Address: %02x:%02x:%02x:%02x:%02x:%02x:%02x:%02x",
                     ieee_addr[7], ieee_addr[6], ieee_addr[5], ieee_addr[4],
                     ieee_addr[3], ieee_addr[2], ieee_addr[1], ieee_addr[0]);
            
#ifdef ZB_ROUTER_ROLE
            ESP_LOGI(TAG, "[JOIN] Device Type: ROUTER (can route messages for other devices)");
#elif defined(ZB_ED_ROLE)
            ESP_LOGI(TAG, "[JOIN] Device Type: END DEVICE");
#else
            ESP_LOGI(TAG, "[JOIN] Device Type: UNKNOWN");
#endif
            
            ESP_LOGI(TAG, "[JOIN] Device is now online and ready");
            
            /* Mark Zigbee connection as successful for OTA validation */
            ota_validation_zigbee_connected();
            
            ESP_LOGI(TAG, "[JOIN] Starting keepalive task and requesting initial state...");
            
            /* Request initial status to populate Zigbee attributes */
            hvac_request_status();
            
            /* Start keepalive task (sends keepalive every 30s to maintain UART connection) */
            esp_zb_scheduler_alarm((esp_zb_callback_t)hvac_keepalive_task, 0, 5000);
            ESP_LOGI(TAG, "[JOIN] Setup complete!");
        } else {
            ESP_LOGW(TAG, "[JOIN] Network steering failed (status: %s)", 
                    esp_err_to_name(err_status));
            ESP_LOGI(TAG, "[JOIN] Retrying network steering in 1 second...");
            esp_zb_scheduler_alarm((esp_zb_callback_t)bdb_start_top_level_commissioning_cb, 
                                  ESP_ZB_BDB_MODE_NETWORK_STEERING, 1000);
        }
        break;

    case ESP_ZB_NLME_STATUS_INDICATION:
        ESP_LOGD(TAG, "[NLME] Network status indication (status: %s)", esp_err_to_name(err_status));
        if (err_status == ESP_OK) {
            ESP_LOGD(TAG, "[NLME] Device successfully connected to network");
            /* Mark Zigbee connection as successful for OTA validation */
            ota_validation_zigbee_connected();
        }
        break;
        
    default:
        ESP_LOGI(TAG, "[ZDO] Signal: %s (0x%x), status: %s", 
                esp_zb_zdo_signal_to_string(sig_type), sig_type,
                esp_err_to_name(err_status));
        break;
    }
}
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
void app_main(void)
{
    ESP_LOGI(OTA_VALIDATION_TAG, "=== Application Starting ===");
    esp_app_desc_t app_desc;
    const esp_partition_t *running = esp_ota_get_running_partition();
    if (esp_ota_get_partition_description(running, &app_desc) == ESP_OK) {
        ESP_LOGI(OTA_VALIDATION_TAG, "Firmware version: %s", app_desc.version);
        ESP_LOGI(OTA_VALIDATION_TAG, "Compile time: %s %s", app_desc.date, app_desc.time);
    }
    ota_validation_start();

    esp_zb_platform_config_t config = {
        .radio_config = ESP_ZB_DEFAULT_RADIO_CONFIG(),
        .host_config = ESP_ZB_DEFAULT_HOST_CONFIG(),
    };
    ESP_ERROR_CHECK(nvs_flash_init());
    ESP_ERROR_CHECK(esp_zb_platform_config(&config));

    // Hardware init
    ESP_LOGI(OTA_VALIDATION_TAG, "Initializing hardware...");
    bool hw_ok = true; // Replace with actual check
    if (hw_ok) {
        ota_validation_hw_init_ok();
    } else {
        ESP_LOGE(OTA_VALIDATION_TAG, "Hardware initialization failed!");
        ota_validation_mark_invalid();
        return;
    }

    // Zigbee stack init
    ESP_LOGI(OTA_VALIDATION_TAG, "Initializing Zigbee stack...");
    bool zigbee_init_ok = true; // Replace with actual check
    if (zigbee_init_ok) {
        ota_validation_zigbee_init_ok();
    } else {
        ESP_LOGE(OTA_VALIDATION_TAG, "Zigbee initialization failed!");
        ota_validation_mark_invalid();
        return;
    }

    // Start Zigbee and wait for connection
    // When Zigbee connects successfully, call:
    // ota_validation_zigbee_connected();

    ESP_LOGI(OTA_VALIDATION_TAG, "=== Application Started ===");

    xTaskCreate(esp_zb_task, "Zigbee_main", 4096, NULL, 5, NULL);
}

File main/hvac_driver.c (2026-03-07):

/*
 * HVAC Driver Implementation
 * 
 * UART communication with ACW02 HVAC device
 */

#include "hvac_driver.h"
#include "esp_log.h"
#include "string.h"
#include "freertos/FreeRTOS.h"
#include "freertos/task.h"
#include "freertos/queue.h"
#include "freertos/semphr.h"
#include "driver/gpio.h"
#include "nvs_flash.h"
#include "nvs.h"

static const char *TAG = "HVAC_DRIVER";
static const char *NVS_NAMESPACE = "hvac_storage";

/* State change callback */
static hvac_state_change_callback_t state_change_callback = NULL;

/* Mutex protecting current_state across tasks */
static SemaphoreHandle_t state_mutex = NULL;

/* Error code mapping structure */
typedef struct {
    uint8_t code_high;  // High byte (ASCII character like 'E', 'P', 'U', etc.)
    uint8_t code_low;   // Low byte (ASCII digit like '0', '1', etc.)
    const char *description;
} error_code_entry_t;

/* Error code lookup table from AIRTON-LIST-ERROR-CODE.EN.pdf */
static const error_code_entry_t error_code_table[] = {
    {'C', 'L', "Filter cleaning reminder"},
    {'D', '0', "Compressor RMS phase current limit"},
    {'D', '1', "Low RMS machine current limit"},
    {'D', '2', "Lower gas discharge temperature limit"},
    {'D', '3', "Extreme anti-freeze limit"},
    {'D', '4', "Overload limit"},
    {'D', '5', "IPM power module temperature limit"},
    {'E', '0', "Protection against high discharge temperatures"},
    {'E', '1', "Overload protection"},
    {'E', '2', "Compressor overload protection"},
    {'E', '3', "Frost protection"},
    {'E', '7', "4-way valve malfunction"},
    {'E', '8', "Abnormal outdoor ambient temperature"},
    {'H', '0', "Compressor stalling or jamming"},
    {'H', '1', "Startup failure"},
    {'H', '2', "Compressor phase current peak protection"},
    {'H', '3', "Compressor phase current RMS protection"},
    {'H', '4', "IPM power module protection"},
    {'H', '5', "IPM overheat protection"},
    {'H', '6', "Compressor circuit phase detection error"},
    {'H', '7', "Compressor phase loss error"},
    {'H', '8', "Outdoor unit fan motor error"},
    {'H', '9', "Outdoor unit fan motor phase current detection circuit error"},
    {'L', '0', "Jumper error"},
    {'L', '1', "Indoor fan motor zero crossing detection circuit malfunction"},
    {'L', '2', "Indoor fan motor error"},
    {'L', '3', "Communication fault between indoor and outdoor unit"},
    {'L', '4', "Port selection error"},
    {'L', '5', "EEPROM error on indoor unit"},
    {'L', '6', "Communication fault between outdoor and indoor unit"},
    {'L', 'L', "Function test"},
    {'P', '0', "EEPROM error on outdoor unit"},
    {'P', '1', "Power on error"},
    {'P', '2', "AC current protection"},
    {'P', '3', "High voltage protection"},
    {'P', '4', "Low voltage protection"},
    {'P', '5', "DC DC line voltage drop protection"},
    {'P', '6', "Current detection circuit error"},
    {'P', '7', "Overcurrent protection"},
    {'P', '8', "PFC current detection circuit error"},
    {'P', '9', "PFC protection"},
    {'P', 'A', "IU and EU mismatch"},
    {'P', 'C', "Fashion Conflict"},
    {'U', '0', "Ambient temperature sensor (probe) open/closed circuit"},
    {'U', '1', "Pipe temperature sensor (probe) open/closed circuit"},
    {'U', '2', "Ambient temperature sensor (probe) open/closed circuit"},
    {'U', '3', "UE Discharge Sensor (Probe) Open/Closed Circuit"},
    {'U', '4', "UE pipe temperature sensor open/closed circuit (probe)"},
    {'U', '5', "IPM power module temperature sensor open/closed circuit"},
    {'U', '6', "Liquid pipe outlet temperature sensor open/closed circuit"},
    {'U', '7', "Gas pipe outlet temperature sensor open/closed circuit"},
    {'U', '8', "Discharge temperature sensor open/closed circuit"},
};

#define ERROR_CODE_TABLE_SIZE (sizeof(error_code_table) / sizeof(error_code_entry_t))

/* Decode error code to human-readable text */
static const char* hvac_decode_error_code(uint8_t code) {
    // Handle special case for filter cleaning (0x80)
    if (code == 0x80) {
        return "Filter cleaning reminder (CL)";
    }
    
    // Handle standard two-byte error codes
    // The code format appears to be: high nibble = letter, low nibble = digit
    // For example: E1 might be encoded differently
    
    // Try to decode assuming ASCII-like encoding
    uint8_t code_high = (code >> 4) & 0x0F;
    uint8_t code_low = code & 0x0F;
    
    // Convert nibbles to ASCII characters
    char high_char = 0, low_char = 0;
    
    // Map high nibble to letter (rough approximation - may need adjustment based on actual protocol)
    if (code_high >= 0x0C && code_high <= 0x0F) {
        high_char = 'C' + (code_high - 0x0C);  // C, D, E, F
    } else if (code_high >= 0x08 && code_high <= 0x0B) {
        high_char = 'H' + (code_high - 0x08);  // H, I, J, K
    } else if (code_high >= 0x04 && code_high <= 0x07) {
        high_char = 'L' + (code_high - 0x04);  // L, M, N, O
    } else if (code_high <= 0x03) {  // 0x00-0x03
        high_char = 'P' + (code_high - 0x00);  // P, Q, R, S
    }
    
    // Map low nibble to digit or letter
    if (code_low <= 9) {
        low_char = '0' + code_low;
    } else {
        low_char = 'A' + (code_low - 10);  // A=10, B=11, C=12, etc.
    }
    
    // Search in lookup table
    for (size_t i = 0; i < ERROR_CODE_TABLE_SIZE; i++) {
        if (error_code_table[i].code_high == high_char && 
            error_code_table[i].code_low == low_char) {
            return error_code_table[i].description;
        }
    }
    
    // If not found in table, return unknown with hex code
    static char unknown_buffer[32];
    snprintf(unknown_buffer, sizeof(unknown_buffer), "Unknown error code 0x%02X", code);
    return unknown_buffer;
}

/* Current HVAC state */
static hvac_state_t current_state = {
    .mode = HVAC_MODE_COOL,
    .power_on = false,
    .target_temp_c = 24,
    .ambient_temp_c = 25,
    .eco_mode = false,
    .night_mode = false,
    .display_on = true,
    .swing_on = false,
    .purifier_on = false,
    .clean_status = false,
    .mute_on = false,
    .fan_speed = HVAC_FAN_AUTO,
    .error = false,
    .error_text = ""  // Empty string when no error
};

/* UART buffer */
static uint8_t rx_buffer[HVAC_UART_BUF_SIZE];
static size_t rx_buffer_len = 0;
static uint32_t last_rx_time = 0;

/* Delayed NVS write to reduce flash wear */
static TimerHandle_t nvs_save_timer = NULL;
static bool nvs_save_pending = false;
#define NVS_SAVE_DELAY_MS  900000  // 900 seconds - write to flash once per 15 minutes max

/* Keepalive frame */
static const uint8_t keepalive_frame[] = {
    0x7A, 0x7A, 0x21, 0xD5, 0x0C, 0x00, 0x00, 0xAB,
    0x0A, 0x0A, 0xFC, 0xF9
};

/* Get status frame */
static const uint8_t get_status_frame[] = {
    0x7A, 0x7A, 0x21, 0xD5, 0x0C, 0x00, 0x00, 0xA2,
    0x0A, 0x0A, 0xFE, 0x29
};
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

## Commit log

2025-10-13 Initial commit for acw02_zb
    [partitions.csv]
2025-10-13 Some updates but still issues
    [esp_zb_hvac.c]
2025-10-13 Reset button use interrupt instead of polling
2025-10-13 Problem Solved: UART Pin Conflict The Issue Your console was freezing at "Boot button initiali�" because:
    HVAC driver was using GPIO 16 & 17
    These are the same pins as the console UART (UART0)
    When HVAC driver called uart_set_pin(), it disconnected the console
    [esp_zb_hvac.c, hvac_driver.c]
2025-10-13 Z2M Custom Switch Converters Added
2025-10-13 Added Fan Mode to Attribute Updates
2025-10-13 Problem: ACW02 has 8 speeds, but Zigbee standard has 7 fan modes
    Solution: Map the 8 ACW02 speeds to the 7 Zigbee modes intelligently:
    Z2M Selection → ACW02 Speed
    off → SILENT (Quiet mode)
    low → P20 (20%)
    medium → P60 (60%)
    high → P100 (100%)
    auto → AUTO
    [esp_zb_hvac.c]
2025-10-13 Correct issues when interviewing device
    [esp_zb_hvac.c]
2025-10-13 Add new EP (NIGHT, PURIFIER, CLEAN and MUTE) Add Night mode switch (Endpoint 5) Add Purifier switch (Endpoint 6) Add Clean status as binary sensor (Endpoint 7) Add Mute switch (Endpoint 8)
2025-10-14 Most of the featues are working. Remaining issues with: - Local temperature (Endpoint: ep1) : Not updated - Running state (Endpoint: ep1) : Stays NULL - settings are not saved when power is cut - Pow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
2025-10-14 Updated current mode
2025-10-14 Summary of what we've accomplished:
    ✅ Running State - Added running_mode attribute to thermostat cluster, properly mapped all HVAC modes
    ✅ Local Temperature - Fixed converter to publish local_temperature_ep1 with proper suffix
    ✅ NVS Persistence - Settings now save to flash and restore on power cycle
    ✅ 13-byte ACK frames - Properly handled to eliminate warnings
    ✅ Z2M Converter - Custom thermostat_ep1 converter with proper _ep# suffixes
    ✅ Clean MQTT payload - Removed duplicate property names
    [esp_zb_hvac.c]
2025-10-14 Add Endpoint 9 - Error Diagnostics Binary Sensor created with:
    Binary status: ON when error/warning present, OFF when clear
    Error text: Human-readable error description (up to 64 characters)
    Custom attribute 0x8000: Zigbee string containing the error message
    ✅ Error Code Lookup Table (53 codes from your CSV):
    Maps error codes like E1, P4, U0, etc. to descriptions
    Example: 0xE1 → "Overload protection"
    ✅ Zigbee2MQTT Integration:
    error_status property (ON/OFF)
    error_text property (readable message)
    Both read-only on endpoint ep9
    Automatic reporting when errors occur
    ✅ Enhanced Error Handling:
    28-byte error frames now populate error_text with descriptions
    Console logs show: "AC FAULT: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
    [esp_zb_hvac.c, hvac_driver.c]
2025-10-14 Update error handling on EP9
    [esp_zb_hvac.c]
2025-10-14 Fix logging bug for ambient temp
    [esp_zb_hvac.c, hvac_driver.c]
2025-10-15 Change Clean status to binary sensor
2025-10-15 Add license section to README
    Added license information for code and PCB files.
2025-10-15 Add Ko-fi support button to README
2025-10-16 Update converter to have only one setpoint AC unit does not have a different setpoint for heating our cooling
2025-10-16 Add error endpoint (Bianry R/O) and device is now a router
    [esp_zb_hvac.c, hvac_driver.c]
2025-10-17 Fix bugs in converter and firmware
    [esp_zb_hvac.c]
2025-10-18 Chnage GPIO for RX/TX (Xiao ESP32-C6)
2025-10-18 Correct PIN number
2025-10-21 Add Gerber file (ordered placed but not tested)
2025-10-21 Add PCB image
2025-10-21 Document PCB details and components used
    Added section about PCB details including components and image.
2025-10-29 Add OTA support
    [partitions.csv]
2025-10-29 Change board type (Devkit with 8MB flash)
2025-10-29 Update baord config to ESP32-C6-DEVKit
2025-10-31 Add OTA app validity check and update partition sizes in configuration
    [partitions.csv]
2025-10-31 Implement OTA validation logic with detailed logging and state management
    [partitions.csv]
2025-11-01 Added the missing call to ota_validation_zigbee_connected() in the network steering success handler.
    [esp_zb_hvac.c]
2025-11-02 Bump project version to 1.2 and reset build number; enhance OTA handling with improved logging and validation; update partition sizes for optimized OTA updates
    [partitions.csv]
2025-11-03 Update project version to 1.3, reset build number, and enhance logging configuration; add board-specific antenna switching definitions
    [esp_zb_hvac.c]
2025-11-04 Update board to ESP32-C6 with LP core
2025-11-13 Refine HVAC state polling logic to detect changes and update Zigbee attributes conditionally; enhance logging for state changes and adjust TX power logging frequency
2025-11-13 Refactor HVAC temperature comparison to use fabsf for improved accuracy; update sdkconfig for optimization settings
2025-11-15 Update version to 1.5 and reset BUILD_NUMBER; implement delayed NVS save to reduce flash wear
    [esp_zb_hvac.c, hvac_driver.c]
2025-11-20 Create PCB version 1.1 - Add two level shifters (as same board will be used for PC-1001 Heat pump controller) - Clear zone around the antenna
    [MP1584EN-LF-Z.step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]
2025-11-20 Update .gitignore to remove unecessary PCB files
2025-11-20 Update .gitignore to exclude additional PCB backup files and remove lock file
2025-11-21 Update HVAC driver to implement state change callback and adjust temperature encoding
2025-11-21 Update HVAC driver to notify Zigbee layer only on state changes; enhance logging for running mode calculations and state updates
2025-11-21 Update HVAC driver to set Zigbee attribute values without notifying on each change, let reporting do its work
2025-11-21 Update HVAC driver to prevent notifying on attribute changes for running mode and fan mode
    [esp_zb_hvac.c]
2025-11-22 Update ACW02 HVAC Thermostat converter to support custom devices (DiY)
2025-11-25 Update HVAC driver to replace filter_dirty with clean_status and adjust build number in CMakeLists
    [esp_zb_hvac.c, hvac_driver.c]
2025-11-25 Remove filter_dirty check from HVAC state decoding logic
2025-11-25 Add initial project files for acw02_zb PCB version 1.2
    [MP1584EN-LF-Z.step, acw02_zb-v1.2.kicad_pcb, acw02_zb-v1.2.kicad_sch]
2025-12-03 Add backup directory for ACW02 PCB version 1.2 to .gitignore
2026-03-07 Update HVAC driver to add error handling and mutex for state management
    [esp_zb_hvac.c, hvac_driver.c]
2026-04-03 Update PCB files (pictures) for ACW02-ZB
2026-04-03 Add bill of materials for ACW02-ZB
    [acw02_zb-v1.1.csv, acw02_zb-v1.2.csv, acw02_zb-v1.2.kicad_pcb]
2026-05-30 Refactor code structure for improved readability and maintainability
    [acw02_zb-v1.2-B_Cu.gbl, acw02_zb-v1.2-B_Mask.gbs, acw02_zb-v1.2-B_Paste.gbp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]

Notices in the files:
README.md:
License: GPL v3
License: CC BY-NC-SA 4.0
